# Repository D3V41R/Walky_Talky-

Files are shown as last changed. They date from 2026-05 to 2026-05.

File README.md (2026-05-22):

**Walky-Talky**

Walky-Talky is a custom **STM32-based** digital voice communication system built for long-range, low-bandwidth voice transmission over LoRa RF.

The project combines embedded firmware development, custom PCB design in KiCad, digital signal processing, and wireless communication into a fully self-contained handheld device.

Voice audio is captured using an INMP441 I2S microphone, compressed in real time using the Codec2 low-bitrate voice codec, and transmitted through a RYLR998 LoRa module operating at 915 MHz. On the receiving side, audio is decoded and played back through a 12-bit DAC and PAM8403 speaker amplifier.

To support continuous real-time streaming, STM32 DMA is used throughout both the audio and RF pipelines, minimizing CPU overhead while maintaining low-latency operation.

The hardware was designed entirely from scratch in KiCad and includes custom analog audio circuitry, rotary encoder channel selection, power regulation, and RF interfacing on a fully custom PCB.

**Features**
-Real-time digital voice communication over LoRa
-Codec2 low-bitrate voice compression
-STM32 DMA-driven audio streaming
-INMP441 I2S microphone input
-12-bit DAC audio playback
-PAM8403 speaker amplifier output
-Rotary encoder channel selection
-Fully custom KiCad PCB design
-Embedded real-time firmware architecture

**System Diagram**



**Hardware Overview**

Schematic:


PCB Renderings: 
WalkieTalkieRnder2
WalkieTalkie

**Technologies Used**
STM32
KiCad
LoRa / RYLR998
Codec2
I2S Audio
DMA Streaming
Embedded C
Digital Signal Processing
Custom PCB Design

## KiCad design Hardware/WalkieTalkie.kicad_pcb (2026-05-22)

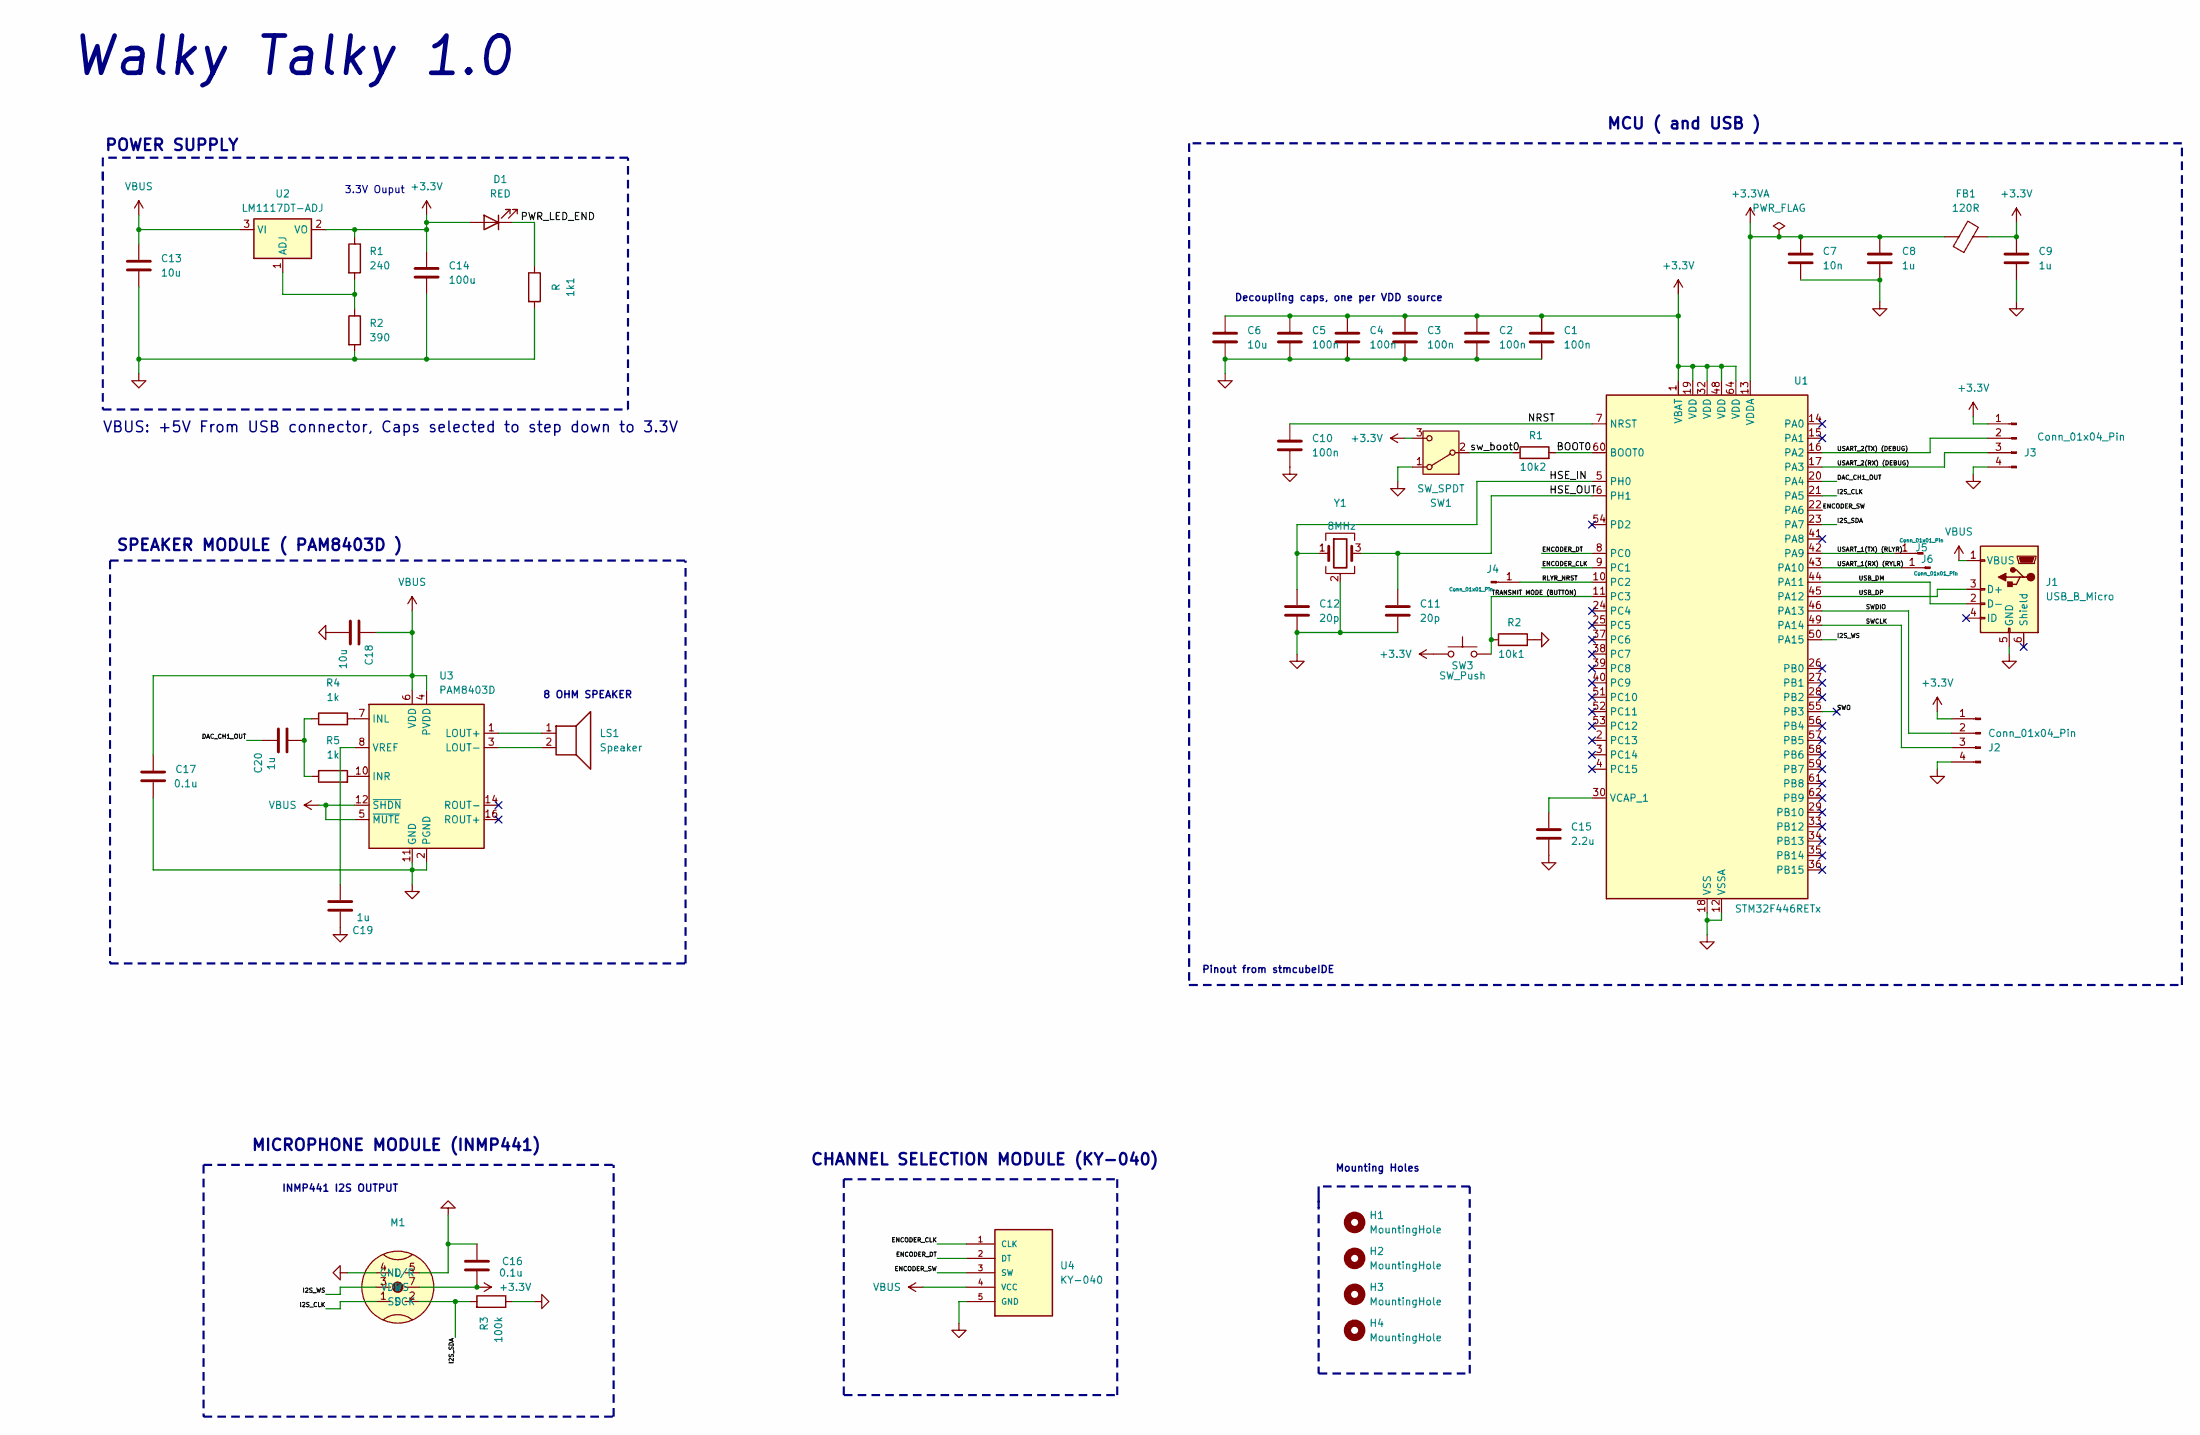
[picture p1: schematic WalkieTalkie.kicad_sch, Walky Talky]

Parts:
1k1: R; R_0603_1608Metric
10k1: R2; R_0603_1608Metric
10k2: R1; R_0603_1608Metric
C1, C2, C3, C4, C5, C10: 100n; C_0603_1608Metric
C6, C13, C18: 10u; C_0603_1608Metric
C7: 10n; C_0603_1608Metric
C8, C9, C19, C20: 1u; C_0603_1608Metric
C11, C12: 20p; C_0603_1608Metric
C14: 100u; C_0603_1608Metric
C15: 2.2u; C_0603_1608Metric
C16, C17: 0.1u; C_0603_1608Metric
D1: RED; LED_0201_0603Metric
FB1: 120R; L_0603_1608Metric
H1, H2, H3, H4: MountingHole; MountingHole_2.2mm_M2
J1: USB_B_Micro; USB_Micro-B_Wuerth_629105150521
J2, J3: Conn_01x04_Pin; PinHeader_1x04_P2.54mm_Vertical
J4, J5, J6: Conn_01x01_Pin; PinSocket_1x01_P2.54mm_Horizontal
LS1: Speaker; PinHeader_1x02_P2.54mm_Vertical
M1: MIC_INMP441ACEZ-R7
R1: 240; R_0603_1608Metric
R2: 390; R_0603_1608Metric
R3: 100k; R_0603_1608Metric
R4, R5: 1k; R_0603_1608Metric
SW1: SW_SPDT; SW_SPDT_PCM12
SW3: SW_Push; SW_DIP_SPSTx01_Slide_6.7x4.1mm_W7.62mm_P2.54mm_LowProfile
U1: STM32F446RETx; LQFP-64_10x10mm_P0.5mm
U2: LM1117DT-ADJ; TO-252-3_TabPin2
U3: PAM8403D; SOIC-16_3.9x9.9mm_P1.27mm
U4: KY-040; PinHeader_1x05_P2.54mm_Vertical
Y1: 8MHz; Crystal_SMD_3225-4Pin_3.2x2.5mm

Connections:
+3.3V: C1.1, C2.1, C3.1, C4.1, C5.1, C6.1, C9.1, C14.1, C16.2, D1.2 (A), FB1.2, J2.1, J3.1, M1.7 (VDD), R1.1, SW1.3 (C), SW3.1, U1.1 (VBAT), U1.19 (VDD), U1.32 (VDD), U1.48 (VDD), U1.64 (VDD), U2.2 (VO)
+3.3VA: C7.1, C8.1, FB1.1, U1.13 (VDDA)
/BOOT0: 10k2.2, U1.60 (BOOT0)
/DAC_CH1_OUT: C20.2, U1.20 (PA4)
/ENCODER_CLK: U1.9 (PC1), U4.1 (CLK)
/ENCODER_DT: U1.8 (PC0), U4.2 (DT)
/ENCODER_SW: U1.22 (PA6), U4.3 (SW)
/HSE_IN: C12.1, U1.5 (PH0), Y1.1
/HSE_OUT: C11.1, U1.6 (PH1), Y1.3
/I2S_CLK: M1.1 (SCK), U1.21 (PA5)
/I2S_SDA: M1.2 (SD), R3.2, U1.23 (PA7)
/I2S_WS: M1.3 (WS), U1.50 (PA15)
/NRST: C10.1, U1.7 (NRST)
/PWR_LED_END: 1k1.1, D1.1 (K)
/RLYR_NRST: J4.1, U1.10 (PC2)
/SWCLK: J2.3, U1.49 (PA14)
/SWDIO: J2.2, U1.46 (PA13)
/SWO: U1.55 (PB3)
/TRANSMIT MODE (BUTTON): 10k1.1, SW3.2, U1.11 (PC3)
/USART_1(RX) (RYLR): J6.1, U1.43 (PA10)
/USART_1(TX) (RLYR): J5.1, U1.42 (PA9)
/USART_2(RX) (DEBUG): J3.3, U1.17 (PA3)
/USART_2(TX) (DEBUG): J3.2, U1.16 (PA2)
/USB_DM: J1.2 (D-), U1.44 (PA11)
/USB_DP: J1.3 (D+), U1.45 (PA12)
/sw_boot0: 10k2.1, SW1.2 (B)
GND: 1k1.2, 10k1.2, C1.2, C2.2, C3.2, C4.2, C5.2, C6.2, C7.2, C8.2, C9.2, C10.2, C11.2, C12.2, C13.2, C14.2, C15.2, C16.1, C17.2, C18.2, C19.2, J1.5 (GND), J2.4, J3.4, M1.4 (L/R), M1.5 (GND), R2.2, R3.1, SW1.1 (A), U1.12 (VSSA), U1.18 (VSS), U1.31 (VSS), U1.47 (VSS), U1.63 (VSS), U3.2 (PGND), U3.11 (GND), U3.15 (PGND), U4.5 (GND), Y1.2 (G), Y1.4 (G)
unnamed: C20.1, R4.1, R5.1
unnamed: C15.1, U1.30 (VCAP_1)
unnamed: R1.2, R2.1, U2.1 (ADJ)
unnamed: R4.2, U3.7 (INL)
unnamed: R5.2, U3.10 (INR)
unnamed: LS1.1, U3.1 (LOUT+)
unnamed: LS1.2, U3.3 (LOUT-)
unnamed: C19.1, U3.8 (VREF)
VBUS: C13.1, C17.1, C18.1, J1.1 (VBUS), U2.3 (VI), U3.4 (PVDD), U3.5 (~MUTE), U3.6 (VDD), U3.12 (~SHDN), U3.13 (PVDD), U4.4 (VCC)

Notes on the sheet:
INMP441 I2S OUTPUT
CHANNEL SELECTION MODULE (KY-040)
VBUS: +5V From USB connector, Caps selected to step down to 3.3V
Pinout from stmcubeIDE
Walky Talky 1.0
MCU ( and USB )
3.3V Ouput
8 OHM SPEAKER
POWER SUPPLY
Decoupling caps, one per VDD source
MICROPHONE MODULE (INMP441)
Mounting Holes
SPEAKER MODULE ( PAM8403D )

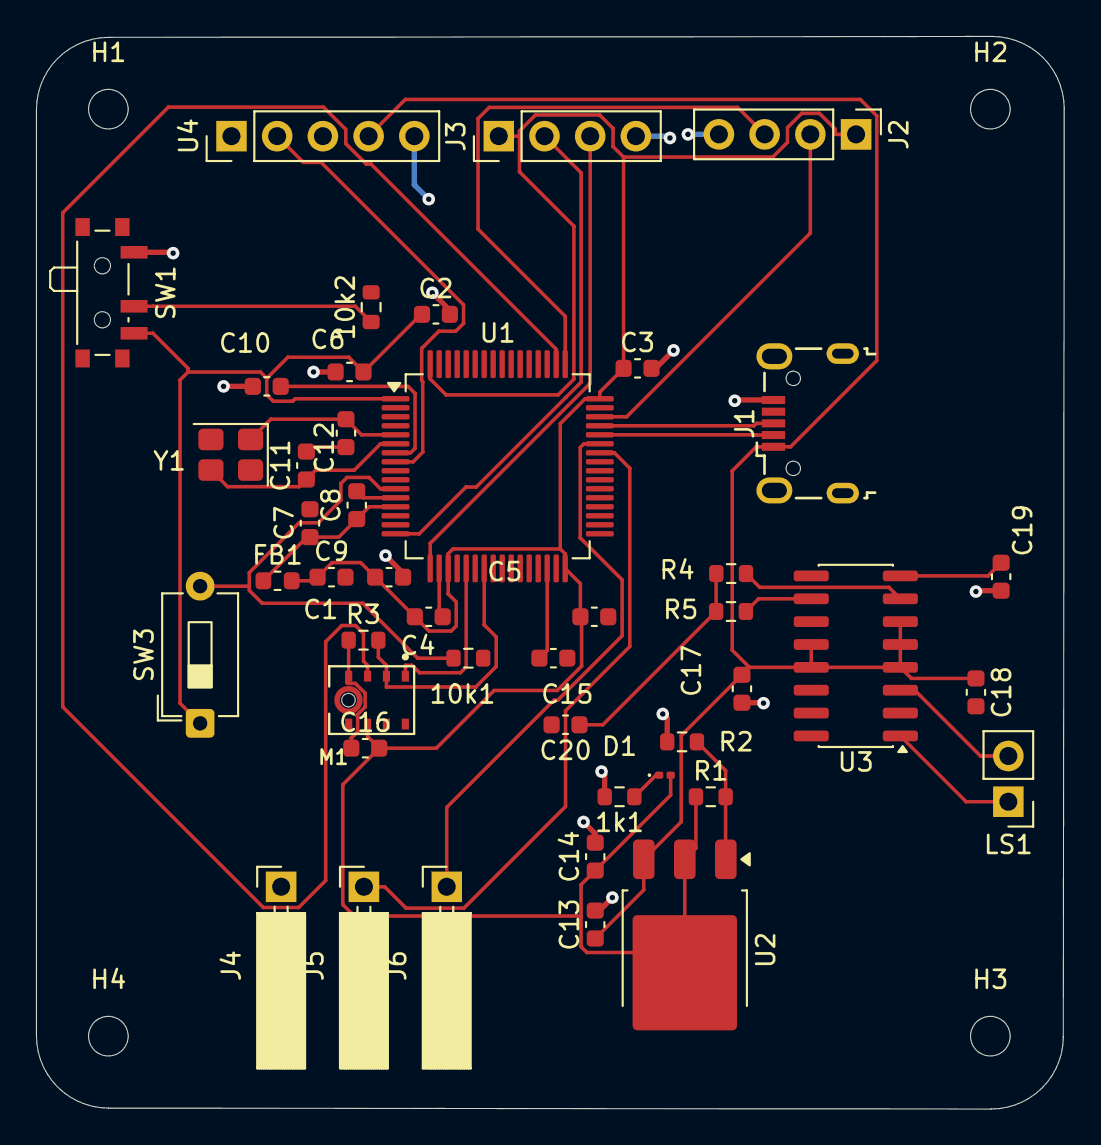
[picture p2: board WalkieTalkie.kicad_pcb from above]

Board: 2 copper layers, 57.1 x 59.6 mm, 49 parts (0 on the bottom side), 35 nets.

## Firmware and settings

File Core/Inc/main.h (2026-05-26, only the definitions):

#define Encoder_DT_Pin GPIO_PIN_0
#define Encoder_DT_GPIO_Port GPIOC
#define Encoder_CLK_Pin GPIO_PIN_1
#define Encoder_CLK_GPIO_Port GPIOC
#define RLYR_NRST_Pin GPIO_PIN_2
#define RLYR_NRST_GPIO_Port GPIOC
#define TRANSMIT_MODE_Pin GPIO_PIN_3
#define TRANSMIT_MODE_GPIO_Port GPIOC
#define DAC_OUTPUT_Pin GPIO_PIN_4
#define DAC_OUTPUT_GPIO_Port GPIOA
#define ENCODER_SW_Pin GPIO_PIN_6
#define ENCODER_SW_GPIO_Port GPIOA
#define TMS_Pin GPIO_PIN_13
#define TMS_GPIO_Port GPIOA
#define TCK_Pin GPIO_PIN_14
#define TCK_GPIO_Port GPIOA
#define SWO_Pin GPIO_PIN_3
#define SWO_GPIO_Port GPIOB

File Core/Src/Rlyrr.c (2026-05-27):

#include "main.h"
#include <string.h>
#include <stdio.h>
#include "codec2.h"

extern UART_HandleTypeDef huart1;
extern uint8_t encoded_bits[8];
extern short decoded_buffer[160];
extern DAC_HandleTypeDef hdac;
extern struct CODEC2 *codec2;

char cmds[256];
uint8_t rxBuffer[128];
uint8_t rx_flag = 0;

void RlyrrInit(void)
{
    HAL_UART_Receive_DMA(&huart1, rxBuffer, sizeof(rxBuffer));

    HAL_Delay(100);
    sprintf(cmds, "AT+ADDRESS=1\r\n");
    HAL_UART_Transmit(&huart1, (uint8_t*)cmds, strlen(cmds), 1000);

    HAL_Delay(100);
    sprintf(cmds, "AT+NETWORKID=5\r\n");
    HAL_UART_Transmit(&huart1, (uint8_t*)cmds, strlen(cmds), 1000);

    HAL_Delay(100);
    sprintf(cmds, "AT+BAND=915000000\r\n");
    HAL_UART_Transmit(&huart1, (uint8_t*)cmds, strlen(cmds), 1000);
}

void RlyrrTransmit(void)
{
    sprintf(cmds, "AT+SEND=2,8,%02X%02X%02X%02X%02X%02X%02X%02X\r\n",
            encoded_bits[0], encoded_bits[1], encoded_bits[2], encoded_bits[3],
            encoded_bits[4], encoded_bits[5], encoded_bits[6], encoded_bits[7]);

    HAL_UART_Transmit(&huart1, (uint8_t*)cmds, strlen(cmds), 1000);
}

void RlyrrReceive(void)
{
    if (strstr((char*)rxBuffer, "+RCV") != NULL)
    {
        char *data_start = strchr((char*)rxBuffer, ',');
        if (data_start) data_start = strchr(data_start + 1, ',');
        if (data_start)
        {
            data_start++;
            for (int i = 0; i < 8; i++)
            {
                char byte_str[3] = {data_start[i*2], data_start[i*2+1], 0};
                encoded_bits[i] = (uint8_t)strtol(byte_str, NULL, 16);
            }
            codec2_decode(codec2, decoded_buffer, encoded_bits);

            HAL_DAC_Start(&hdac, DAC_CHANNEL_1);
            for (int i = 0; i < 160; i++)
            {
                uint16_t dac_val = (decoded_buffer[i] + 32768) >> 4;
                HAL_DAC_SetValue(&hdac, DAC_CHANNEL_1, DAC_ALIGN_12B_R, dac_val);
                HAL_Delay(1);
            }
        }
        memset(rxBuffer, 0, sizeof(rxBuffer));
    }
}

void HAL_UART_RxCpltCallback(UART_HandleTypeDef *huart)
{
    if (huart->Instance == USART1)
    {
        rx_flag = 1;
        HAL_UART_Receive_DMA(&huart1, rxBuffer, sizeof(rxBuffer));
    }
}

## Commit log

2026-05-22 Added Hardware Design Files
    [WalkieTalkie.kicad_pcb, WalkieTalkie.kicad_sch]
2026-05-22 Rename WalkieTalkie.kicad_pro to Hardware /WalkieTalkie.kicad_pro
2026-05-27 Implemented Rlyrr Driver, Completed Microphone Driver.

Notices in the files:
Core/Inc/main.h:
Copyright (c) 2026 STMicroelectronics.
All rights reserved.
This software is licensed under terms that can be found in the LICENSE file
